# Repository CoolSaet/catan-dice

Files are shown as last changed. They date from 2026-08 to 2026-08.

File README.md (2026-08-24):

# Catan Dice – ESP8266 D1 Mini

A physical dice-roller for Catan.  
Press the button → the ESP performs an HTTP GET to a configured URL (your game server / smart home integration).

## Hardware

| Component | D1 Mini pin | Notes |
|---|---|---|
| Roll button | **D5** (GPIO 14) | Active LOW, internal pull-up enabled |

The roll button uses the D1 Mini's internal pull-up, so no external pull-up resistor is
needed.

### Assembly and Wiring

1. Stack the Wemos Li-ion Battery Shield on top of the Wemos D1 Mini.
2. Wire the push-button switch between **D5** (GPIO 14) and **GND**.
3. Wire the button LED between **GND** and **5V** on the battery shield.
4. Connect the battery to the battery shield. Cut the battery's positive wire and put the
	SPST switch in series between the two cut ends. Adding connectors to the battery cable can
	make this connection easier and allow the battery to be disconnected.

The switch must be turned on for the battery to charge. To charge the battery, connect a USB
cable to the USB port on the battery shield while the switch is on.

### Hardware Used

All hardware was bought at [TinyTronics](https://tinytronics.nl/):

* PKCELL Li-Po Battery 3.7V 2000mAh – JST-PH – LP803860
* Metal Push Button 16mm – Reset – with 3-6V Green LED – with Cable
* Xurui XT-11A Toggle Switch – SPST
* Wemos Li-ion Battery Shield for D1 Mini (Lolin v1.3.0)
* Wemos D1 Mini V4 – ESP8266 – CH340 (Lolin)

## Features

* **AP mode** – the ESP creates its own WiFi network so you can connect without a router.
* **STA mode** – the ESP connects to your home WiFi.
* **Dual STA profiles** – configure two STA WiFi profiles and choose which one is tried first.
* **STA fallback order** – try selected primary STA profile, then the other profile, then AP mode.
* The first STA profile is by default configured for the smart-catan ad hoc access point. See [CoolSaet/smart-catan](https://github.com/CoolSaet/smart-catan).
* Separate roll URLs for AP and STA modes.
* Web UI served from LittleFS to configure SSIDs, passwords and URLs at runtime.
* HTTP Basic Authentication protects the web UI, configuration API and browser roll endpoint.
* Config persisted in `/config.json` on the filesystem (survives reboots).
* Roll button is debounced (50 ms).

## Building & Flashing

Install [PlatformIO](https://platformio.org/).

```bash
# Build firmware
pio run

# Upload firmware
pio run -t upload

# Upload web UI (data/ folder) to LittleFS
pio run -t uploadfs

# Monitor serial output
pio device monitor
```

## Web UI

After flashing, connect to the ESP's IP address in a browser:

* **AP mode** – connect to the `CatanDice` WiFi, then open `http://192.168.4.1/`
* **STA mode** – find the IP from serial monitor or your router, then open `http://<ip>/`

The browser will prompt for the web username and password. The default credentials are:

* Username: `admin`
* Password: `catandice`

Change the web password from the **Web Server Authentication** section. The password field is
blank and locked until its **Change** button is clicked. A web password must contain at least
8 characters, and an empty web username is rejected.

HTTP Basic Authentication protects all web routes. Credentials are not encrypted because the
ESP serves HTTP rather than HTTPS, so use this on a trusted local network. Change the default
password before using the device on a network where other users may connect.

### REST API

| Method | Path | Description |
|---|---|---|
| `GET`  | `/config` | Returns non-secret configuration as JSON |
| `POST` | `/config` | Update configuration (JSON body) |
| `POST` | `/roll` | Trigger a dice roll from browser |

All API requests require valid HTTP Basic Authentication. `GET /config` never returns the AP,
STA, or web-server passwords. The web UI only includes a password in `POST /config` after that
password's **Change** button has been clicked; otherwise the stored password is left unchanged.
The username is returned by `GET /config` because it is not secret.

Example request:

```bash
curl --user admin:catandice http://192.168.4.1/config
```

## Default Configuration

| Setting | Default |
|---|---|
| AP SSID | `CatanDice` |
| AP Password | `catandice` |
| First STA profile SSID | `LocalCatanWiFi` (smart-catan ad hoc access point) |
| Local Catan WiFi password | `LocalCatanPass` |
| Local Catan WiFi roll URL | `http://192.168.4.1/rollDice` |
| Home WiFi SSID | *(empty)* |
| Home WiFi password | *(empty)* |
| Home WiFi roll URL | `http://catan.mydomain.eu/rollDice` |
| Primary STA profile | Local Catan WiFi |
| Web username | `admin` |
| Web password | `catandice` |

Passwords are stored in `/config.json` on LittleFS so they survive reboots, but they are not
sent back through `GET /config`. Existing configuration files without web credentials use the
defaults above.

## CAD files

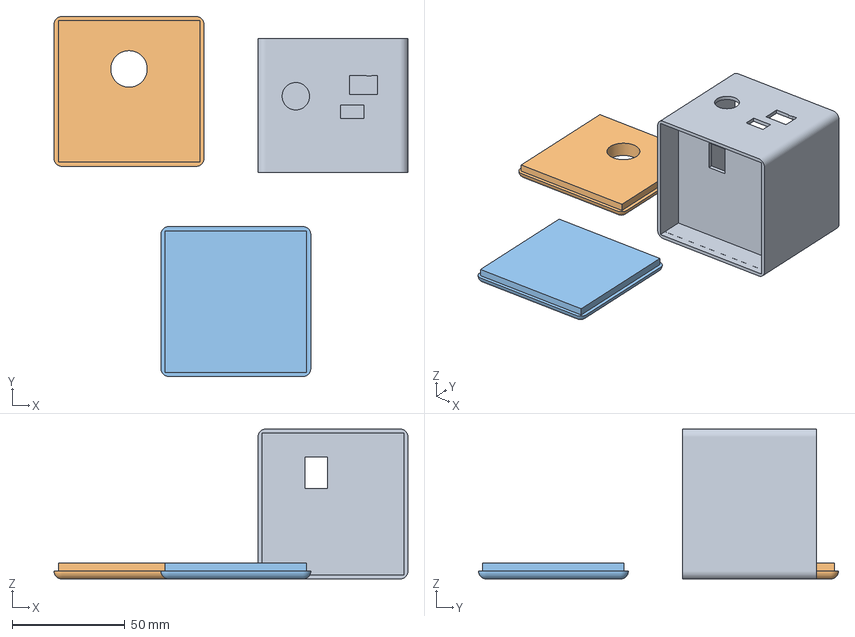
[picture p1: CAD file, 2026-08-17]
3d/Dice_w_Battery.3mf
157.2 x 159.9 x 66.6 mm
top_lid
bottom_lid

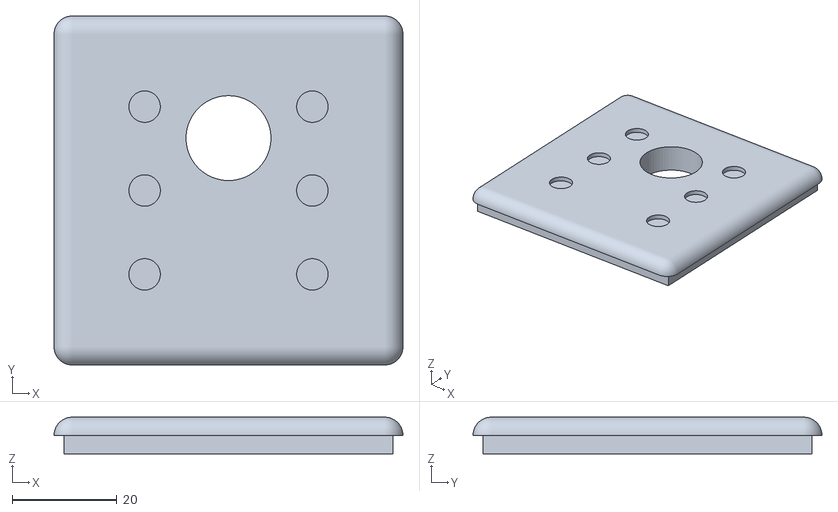
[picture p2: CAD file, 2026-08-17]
3d/top_lid.stl
66.6 x 66.6 x 7.00

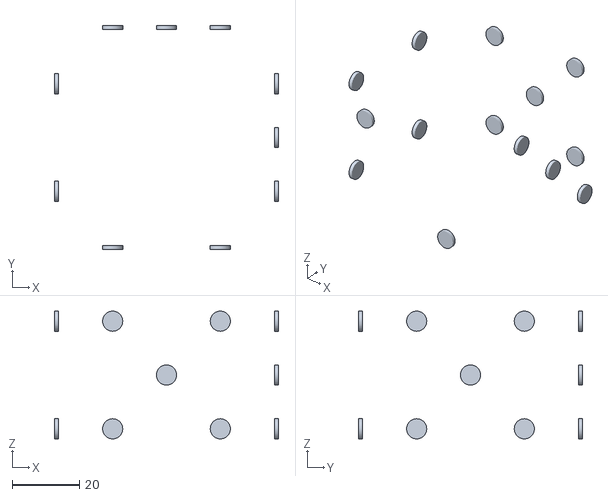
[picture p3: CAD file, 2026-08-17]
3d/body_pips.stl
66.6 x 66.6 x 38.0

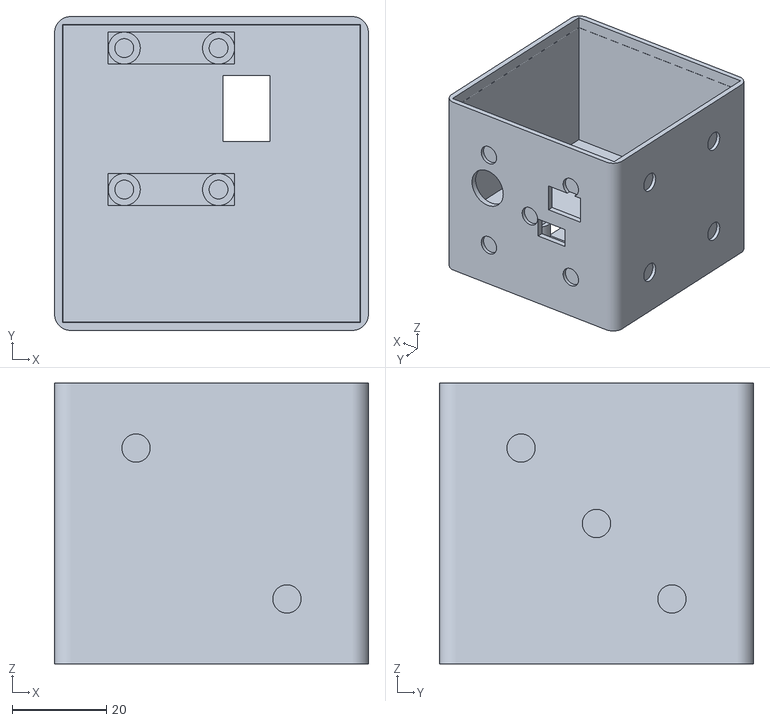
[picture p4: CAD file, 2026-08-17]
3d/body.stl
66.6 x 66.6 x 59.6

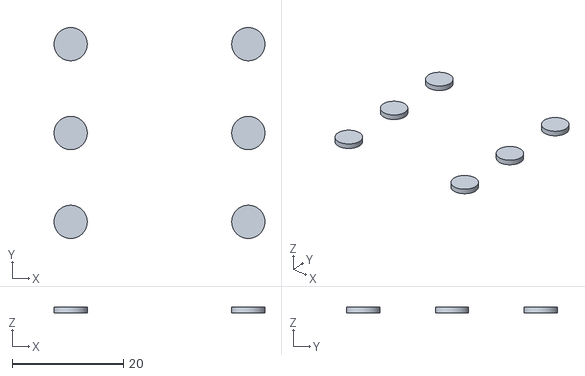
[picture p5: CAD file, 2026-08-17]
3d/top_lid_pips.stl
38.0 x 38.0 x 1.15

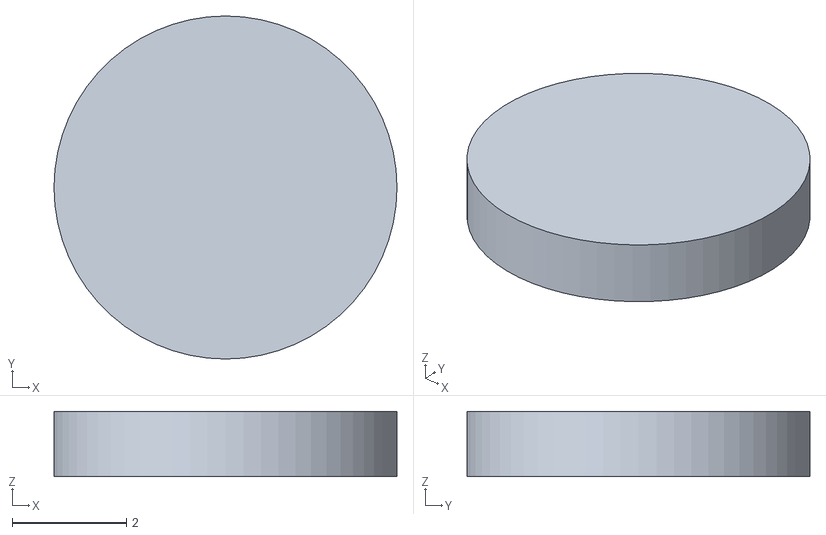
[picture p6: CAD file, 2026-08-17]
3d/bottom_lid_pips.stl
6.00 x 6.00 x 1.15

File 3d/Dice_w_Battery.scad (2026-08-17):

// ==========================================
// PARAMETRIC AMS DICE ENCLOSURE 
// (12.5mm ROUND SWITCH + EXTRA WEMOS CLEARANCE)
// ==========================================
$fn = 60; // Smoothness for circles/cylinders

/* [Render Selection] */
part = "all"; // [body_ams: Main Body (Color 1), pips_ams: All Pips (Color 2), top_lid_ams: Top Lid (Color 1), top_pips_ams: Top Lid Pips (Color 2), bottom_lid_ams: Bottom Lid (Color 1), bottom_pip_ams: Bottom Lid Pip (Color 2), all: Color Preview]

/* [Core Dimensions] */
inner_size    = 63.0; // 63mm internal cavity for 2000mAh battery
wall_thick    = 1.8;  // Wall thickness
dice_size     = inner_size + (2 * wall_thick); // 66.6mm outer cube
corner_rad    = 3.5;  // Outer rounded corner/edge radius (mm)

/* [AMS Pip Specs] */
pip_dia       = 6.0;  
pip_depth     = 0.8;  // Flush skin depth

/* [Internal Compartments] */
bat_bay_h     = 17.0; 
floor_thick   = 2.0;  

/* [Board Specs - Matched to Photo] */
wemos_w       = 25.8; // Board width
wemos_l       = 34.4; // Board length
pcb_thick     = 1.6;  
standoff_h    = 8.0;  // Standoff height above internal floor

// Mounting Holes & Threaded Inserts (Opposite USB Port)
insert_hole_dia = 4.0; // Pilot hole for M2 heat-set insert
insert_depth    = 5.0; // Depth for heat-set insert
standoff_dia    = 6.8; // Outer diameter of standoff pillar
v4_hole_spacing = 20.0; // Distance between mounting holes

// Board & Switch Layout Offsets
wemos_x_shift = -8.5; // Shifted 8.5mm to the left to free up room for chunky switch
wemos_y_shift = (inner_size/2) - (wemos_l/2) - 0.5; // Micro-USB flush against back wall
switch_x_pos  = 16.5; // Positioned on the right side of the back wall

// Ports & Cutouts
usb_c_w         = 10.5; // Micro-USB port cutout width
usb_c_h         = 6.0;  // Micro-USB port cutout height
usb_w         = 12.5; // Micro-USB port cutout width
usb_h         = 8.5;  // Micro-USB port cutout height
button_dia    = 16.2; // Top lid button hole diameter
switch_dia    = 12.2; // Round power switch hole diameter

/* [Lid Parameters] */
lid_thick     = 3.5;  // Matches corner_rad for smooth curvature transition
lip_height    = 3.5;  
clearance     = 0.15; 

// ==========================================
// RENDER CONTROL
// ==========================================

if (part == "body_ams") {
    difference() {
        dice_body();
        side_pips();
    }
} else if (part == "pips_ams") {
    intersection() {
        outer_block(dice_size - 2*lid_thick);
        side_pips();
    }
} else if (part == "top_lid_ams") {
    difference() {
        top_lid();
        top_side6_pips();
    }
} else if (part == "top_pips_ams") {
    intersection() {
        top_lid_outer();
        top_side6_pips();
    }
} else if (part == "bottom_lid_ams") {
    difference() {
        bottom_lid();
        bottom_side1_pip();
    }
} else if (part == "bottom_pip_ams") {
    intersection() {
        bottom_lid_outer();
        bottom_side1_pip();
    }
} else if (part == "all") {
    // Multi-Material Color Preview
    color("DarkSlateGray") difference() { dice_body(); side_pips(); }
    color("White") intersection() { outer_block(dice_size - 2*lid_thick); side_pips(); }
    
    translate([0, 0, dice_size/2 + 12]) {
        color("DarkSlateGray") difference() { top_lid(); top_side6_pips(); }
        color("White") intersection() { top_lid_outer(); top_side6_pips(); }
    }
    
    translate([0, 0, -dice_size/2 - 12]) {
        color("DarkSlateGray") difference() { bottom_lid(); bottom_side1_pip(); }
        color("White") intersection() { bottom_lid_outer(); bottom_side1_pip(); }
    }
}

// ==========================================
// MODULES & GEOMETRY
// ==========================================

module outer_shell() {
    minkowski() {
        cube([dice_size - 2*corner_rad, dice_size - 2*corner_rad, dice_size - 2*corner_rad], center=true);
        sphere(r=corner_rad);
    }
}

module outer_block(h_val) {
    linear_extrude(height=h_val, center=true)
        offset(r=corner_rad)
            square([dice_size - 2*corner_rad, dice_size - 2*corner_rad], center=true);
}

module top_lid_outer() {
    intersection() {
        outer_shell();
        translate([0, 0, dice_size/2 - lid_thick/2 + 0.01])
            cube([dice_size + 10, dice_size + 10, lid_thick + 0.02], center=true);
    }
}

module bottom_lid_outer() {
    intersection() {
        outer_shell();
        translate([0, 0, -dice_size/2 + lid_thick/2 - 0.01])
            cube([dice_size + 10, dice_size + 10, lid_thick + 0.02], center=true);
    }
}

module dice_body() {
    floor_z = -dice_size/2 + wall_thick + bat_bay_h;
    body_h = dice_size - 2*lid_thick;
    
    difference() {
        // Outer Body Wall
        outer_block(body_h);
        
        // Inner Cavity
        cube([inner_size, inner_size, inner_size], center=true);
            
        // Top Lid Lip Recess
        translate([0, 0, body_h/2 - lip_height/2 + 0.1])
            cube([inner_size + clearance, inner_size + clearance, lip_height + 0.2], center=true);

        // Bottom Lid Lip Recess
        translate([0, 0, -body_h/2 + lip_height/2 - 0.1])
            cube([inner_size + clearance, inner_size + clearance, lip_height + 0.2], center=true);

        // --- PORTS & CUTOUTS ---

        // Wire Pass-Through Cutout in Middle Floor
        translate([wemos_x_shift + wemos_w/2 + 3, wemos_y_shift, floor_z])
            cube([10, 14, floor_thick * 3], center=true);

        // Micro-USB-C Port Cutout (Shifted with Wemos)
        translate([wemos_x_shift, dice_size/2, floor_z + floor_thick + standoff_h + pcb_thick ])
            cube([usb_c_w, wall_thick * 3, usb_c_h], center=true);

    // Micro-USB Shield Port Cutout (Shifted with Wemos)
        translate([wemos_x_shift + -5, dice_size/2, floor_z + floor_thick + standoff_h + pcb_thick + 12 ])
            cube([usb_w, wall_thick * 3, usb_h], center=true);


        // 12.5mm Round Power Switch Cutout
        translate([switch_x_pos, dice_size/2, floor_z + floor_thick + standoff_h + pcb_thick + 7.0])
            rotate([90, 0, 0])
                cylinder(d=switch_dia, h=wall_thick * 3, center=true);
    }
    
    // Internal Divider Floor + Integrated Standoffs
    translate([0, 0, floor_z]) {
        difference() {
            union() {
                // Main Divider Plate
                cube([inner_size, inner_size, floor_thick], center=true);
                
                // Threaded Insert Standoffs attached directly onto middle plate
                translate([wemos_x_shift, wemos_y_shift, floor_thick/2]) {
                    wemos_v4_standoffs();
                }
                
                // Threaded Insert Standoffs attached directly onto middle plate
                translate([wemos_x_shift, wemos_y_shift+30, floor_thick/2]) {
                    wemos_v4_standoffs();
                }
            }
            
            // Re-apply Battery Wire Pass-Through Hole
            translate([wemos_x_shift + wemos_w/2 + 3, wemos_y_shift, 0])
                cube([10, 14, floor_thick * 4], center=true);
        }
    }
}

module wemos_v4_standoffs() {
    hole_y_pos = -wemos_l/2 ; 

    difference() {
        union() {
            // Reinforcing Base Plate tied to middle floor
            translate([0, hole_y_pos, 1.0])
                cube([v4_hole_spacing + standoff_dia, standoff_dia, 2.0], center=true);

            // 2 Standoff Pillars
            for (x = [-v4_hole_spacing/2, v4_hole_spacing/2]) {
                translate([x, hole_y_pos, standoff_h/2])
                    cylinder(d=standoff_dia, h=standoff_h, center=true);
            }
        }
        
        // Heat-Set Insert Pilot Holes
        for (x = [-v4_hole_spacing/2, v4_hole_spacing/2]) {
            translate([x, hole_y_pos, standoff_h - insert_depth/2 + 0.1])
                cylinder(d=insert_hole_dia, h=insert_depth + 0.2, center=true);
        }
    }
}
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

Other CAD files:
3d/bottom_lid.stl

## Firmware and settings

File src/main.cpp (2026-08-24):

/*
 * Catan Dice - ESP8266 D1 Mini
 *
 * Hardware:
 *   - Switch on D5 (GPIO14): LOW = AP mode, HIGH = STA (home WiFi) mode
 *   - Push button on D6 (GPIO12): active LOW (pull-up), rolls the dice (HTTP GET)
 *
 * Configuration is stored in LittleFS as /config.json
 * Web UI is served from LittleFS (/index.html)
 */

#include <Arduino.h>
#include <ESP8266WiFi.h>
#include <ESP8266WebServer.h>
#include <ESP8266HTTPClient.h>
#include <WiFiClient.h>
#include <LittleFS.h>
#include <ArduinoJson.h>

// Constants for button debounce state
static bool     lastButtonState  = HIGH;
static unsigned long lastDebounce = 0;
static const unsigned long DEBOUNCE_MS = 50;

// Pin definitions 
static const uint8_t PIN_BUTTON      = D5; // active LOW (Push button to roll dice)

// Config defaults
struct Config {
    // Ad-hoc AP mode
    char apSsid[32]     = "CatanDice";
    char apPassword[64] = "catandice";

    // STA profile 1 (home WiFi)
    char staLocalCatanSsid[32]     = "LocalCatanWiFi";
    char staLocalCatanPassword[64] = "LocalCatanPass";

    // STA profile 2 (secondary WiFi)
    char staHomeSsid[32]     = "";
    char staHomePassword[64] = "";

    // Preferred first profile when connecting in STA mode (1 or 2)
    uint8_t staPrimary    = 1;

    char urlLocalCatanSta[256] = "http://192.168.4.1/rollDice"; // called when in STA mode
    char urlHomeSta[256]       = "http://catan.mydomain.eu/rollDice"; // called when in STA mode

    // Web server HTTP Basic Auth credentials
    char webUsername[32] = "admin";
    char webPassword[64] = "catandice";
};

static Config cfg;
static ESP8266WebServer server(80);
static bool apMode = false;
static uint8_t connectedProfile = 0; // 0= Ad-hoc AP, 1= Local Catan STA, 2= Home STA

// Config persistence
static const char* CONFIG_FILE = "/config.json";

void loadConfig() {
    if (!LittleFS.exists(CONFIG_FILE)) return;
    File f = LittleFS.open(CONFIG_FILE, "r");
    if (!f) return;

    StaticJsonDocument<1024> doc;
    if (deserializeJson(doc, f) != DeserializationError::Ok) { f.close(); return; }
    f.close();

    strlcpy(cfg.apSsid,                 doc["apSsid"]                   | cfg.apSsid,               sizeof(cfg.apSsid));
    strlcpy(cfg.apPassword,             doc["apPassword"]               | cfg.apPassword,           sizeof(cfg.apPassword));
    strlcpy(cfg.staLocalCatanSsid,      doc["staLocalCatanSsid"]        | cfg.staLocalCatanSsid,    sizeof(cfg.staLocalCatanSsid));
    strlcpy(cfg.staLocalCatanPassword,  doc["staLocalCatanPassword"]    | cfg.staLocalCatanPassword,sizeof(cfg.staLocalCatanPassword));
    strlcpy(cfg.staHomeSsid,            doc["staHomeSsid"]              | cfg.staHomeSsid,          sizeof(cfg.staHomeSsid));
    strlcpy(cfg.staHomePassword,        doc["staHomePassword"]          | cfg.staHomePassword,      sizeof(cfg.staHomePassword));
    strlcpy(cfg.urlLocalCatanSta,       doc["urlLocalCatanSta"]         | cfg.urlLocalCatanSta,     sizeof(cfg.urlLocalCatanSta));
    strlcpy(cfg.urlHomeSta,             doc["urlHomeSta"]               | cfg.urlHomeSta,           sizeof(cfg.urlHomeSta));    
    strlcpy(cfg.webUsername,            doc["webUsername"]              | cfg.webUsername,          sizeof(cfg.webUsername));
    strlcpy(cfg.webPassword,            doc["webPassword"]              | cfg.webPassword,          sizeof(cfg.webPassword));
    
    cfg.staPrimary = doc["staPrimary"] | cfg.staPrimary;
    if (cfg.staPrimary != 1 && cfg.staPrimary != 2) cfg.staPrimary = 1;

}

void saveConfig() {
    File f = LittleFS.open(CONFIG_FILE, "w");
    if (!f) return;

    StaticJsonDocument<1024> doc;
    doc["apSsid"]      = cfg.apSsid;
    doc["apPassword"]  = cfg.apPassword;
    doc["staLocalCatanSsid"]     = cfg.staLocalCatanSsid;
    doc["staLocalCatanPassword"] = cfg.staLocalCatanPassword;
    doc["staHomeSsid"]    = cfg.staHomeSsid;
    doc["staHomePassword"] = cfg.staHomePassword;
    doc["staPrimary"]  = cfg.staPrimary;
    doc["urlLocalCatanSta"] = cfg.urlLocalCatanSta;
    doc["urlHomeSta"]       = cfg.urlHomeSta;
    doc["webUsername"]      = cfg.webUsername;
    doc["webPassword"]      = cfg.webPassword;

    serializeJson(doc, f);
    f.close();
}

// HTTP GET to roll URL 
void rollDice() {

    // Get the URL to call based on the connected profile
    const char* url = nullptr;
    if (connectedProfile == 1){
        url = cfg.urlLocalCatanSta;
    }else if (connectedProfile == 2){
        url = cfg.urlHomeSta;
    } else {
        Serial.println("[roll] Not in STA mode, skipping roll");
        return;
    }

    if (strlen(url) == 0) {
        Serial.println("[roll] URL not configured");
        return;
    }
    Serial.printf("[roll] GET %s\n", url);

    WiFiClient client;
    HTTPClient http;
    if (http.begin(client, url)) {
        int code = http.GET();
        Serial.printf("[roll] response: %d\n", code);
        http.end();
    } else {
        Serial.println("[roll] http.begin() failed");
    }
}

//  Web UI handlers 
bool requireAuthentication() {
    if (server.authenticate(cfg.webUsername, cfg.webPassword)) return true;
    server.requestAuthentication();
    return false;
}

void handleRoot() {
    if (!requireAuthentication()) return;
    if (LittleFS.exists("/index.html")) {
        File f = LittleFS.open("/index.html", "r");
        server.streamFile(f, "text/html");
        f.close();
    } else {
        server.send(200, "text/plain", "UI not found. Flash filesystem.");
    }
}

void handleGetConfig() {
    if (!requireAuthentication()) return;

    StaticJsonDocument<1024> doc;
    doc["apSsid"]                   = cfg.apSsid;
    doc["staLocalCatanSsid"]        = cfg.staLocalCatanSsid;
    doc["staHomeSsid"]              = cfg.staHomeSsid;
    doc["staPrimary"]               = cfg.staPrimary;
    doc["urlLocalCatanSta"]         = cfg.urlLocalCatanSta;
    doc["urlHomeSta"]               = cfg.urlHomeSta;
    doc["webUsername"]              = cfg.webUsername;
    doc["mode"]                     = apMode ? "ap" : "sta";

    String out;
    serializeJson(doc, out);
    server.send(200, "application/json", out);
}

void handleSaveConfig() {
    if (!requireAuthentication()) return;
    if (!server.hasArg("plain")) { server.send(400, "text/plain", "No body"); return; }

    StaticJsonDocument<1024> doc;
    if (deserializeJson(doc, server.arg("plain")) != DeserializationError::Ok) {
        server.send(400, "text/plain", "Invalid JSON");
        return;
    }

    if (doc.containsKey("apSsid"))                  strlcpy(cfg.apSsid,                 doc["apSsid"],                  sizeof(cfg.apSsid));
    if (doc.containsKey("apPassword"))              strlcpy(cfg.apPassword,             doc["apPassword"],              sizeof(cfg.apPassword));
    if (doc.containsKey("staLocalCatanSsid"))       strlcpy(cfg.staLocalCatanSsid,      doc["staLocalCatanSsid"],       sizeof(cfg.staLocalCatanSsid));
    if (doc.containsKey("staLocalCatanPassword"))   strlcpy(cfg.staLocalCatanPassword,  doc["staLocalCatanPassword"],   sizeof(cfg.staLocalCatanPassword));
    if (doc.containsKey("staHomeSsid"))             strlcpy(cfg.staHomeSsid,            doc["staHomeSsid"],             sizeof(cfg.staHomeSsid));
    if (doc.containsKey("staHomePassword"))         strlcpy(cfg.staHomePassword,        doc["staHomePassword"],         sizeof(cfg.staHomePassword));
    if (doc.containsKey("staPrimary")) {
        int primary = doc["staPrimary"];
        if (primary == 1 || primary == 2) cfg.staPrimary = primary;
    }
    if (doc.containsKey("urlLocalCatanSta")) strlcpy(cfg.urlLocalCatanSta, doc["urlLocalCatanSta"], sizeof(cfg.urlLocalCatanSta));
    if (doc.containsKey("urlHomeSta"))       strlcpy(cfg.urlHomeSta,       doc["urlHomeSta"],       sizeof(cfg.urlHomeSta));
    if (doc.containsKey("webUsername")) {
        const char* username = doc["webUsername"] | "";
        if (strlen(username) == 0) {
            server.send(400, "text/plain", "Web username cannot be empty");
            return;
        }
        strlcpy(cfg.webUsername, username, sizeof(cfg.webUsername));
    }
    if (doc.containsKey("webPassword")) {
        const char* password = doc["webPassword"] | "";
        if (strlen(password) < 8) {
            server.send(400, "text/plain", "Web password must be at least 8 characters");
            return;
        }
        strlcpy(cfg.webPassword, password, sizeof(cfg.webPassword));
    }

    saveConfig();
    server.send(200, "application/json", "{\"status\":\"ok\"}");
}

void handleRoll() {
    if (!requireAuthentication()) return;
    rollDice();
    server.send(200, "application/json", "{\"status\":\"rolling\"}");
}

// WiFi setup
void startAP() {
    WiFi.mode(WIFI_AP);
    WiFi.softAP(cfg.apSsid, cfg.apPassword);
    Serial.printf("[wifi] AP started: SSID=%s  IP=%s\n",
                  cfg.apSsid, WiFi.softAPIP().toString().c_str());
}


// Connect to STA profile, returns true if connected
bool connectSTAProfile(const char* label, const char* ssid, const char* password) {
    if (strlen(ssid) == 0) {
        Serial.printf("[wifi] %s skipped (empty SSID)\n", label);
        return false;
    }

    WiFi.begin(ssid, password);
    Serial.printf("[wifi] Connecting (%s) to %s", label, ssid);
    unsigned long t = millis();
    while (WiFi.status() != WL_CONNECTED && millis() - t < 15000) {
        delay(500);
        Serial.print('.');
    }

    if (WiFi.status() == WL_CONNECTED) {
        Serial.printf("\n[wifi] Connected (%s) IP=%s\n", label, WiFi.localIP().toString().c_str());
        return true;
    }

    Serial.printf("\n[wifi] %s failed\n", label);
    WiFi.disconnect();
    delay(100);
    return false;
}

// Start STA mode, try both profiles, fallback to AP if both fail
void startSTA() {
    WiFi.mode(WIFI_STA);

    bool connected = false;
    if (cfg.staPrimary == 2) {
        connected = connectSTAProfile("STA Home Profile", cfg.staHomeSsid, cfg.staHomePassword);
        if (connected) {connectedProfile = 2;}
        if (!connected) {
            connected = connectSTAProfile("STA Local Catan Profile", cfg.staLocalCatanSsid, cfg.staLocalCatanPassword);
            if (connected) {connectedProfile = 1;}
        }
    } else {
        connected = connectSTAProfile("STA Local Catan Profile", cfg.staLocalCatanSsid, cfg.staLocalCatanPassword);
        if (connected) {connectedProfile = 1;}
        if (!connected) {
            connected = connectSTAProfile("STA Home Profile", cfg.staHomeSsid, cfg.staHomePassword);
            if (connected) {connectedProfile = 2;}
        }
    }

    if (!connected) {
        Serial.println("\n[wifi] STA failed, falling back to AP");
        startAP();
        apMode = true;
        connectedProfile = 0; // Ad-hoc AP
    } else {
        apMode = false;
    }
}

// Arduino entry points
void setup() {
    Serial.begin(115200);
    delay(200);

    // Configure button pin
    pinMode(PIN_BUTTON,      INPUT_PULLUP);

    // Mount LittleFS and load config
    if (!LittleFS.begin()) {
        Serial.println("[fs] LittleFS mount failed");
    }
    loadConfig();

    // Start WiFi in STA, if fails, fallback to AP mode
    startSTA();

    // Setup HTTP server routes
    server.on("/",           HTTP_GET,  handleRoot);
    server.on("/config",     HTTP_GET,  handleGetConfig);
    server.on("/config",     HTTP_POST, handleSaveConfig);
    server.on("/roll",       HTTP_POST, handleRoll);

    // Serve static files from LittleFS
    server.onNotFound([]() {
        if (!requireAuthentication()) return;
        String path = server.uri();
        if (LittleFS.exists(path)) {
            File f = LittleFS.open(path, "r");
            String mime = "text/plain";
            if (path.endsWith(".html")) mime = "text/html";
            else if (path.endsWith(".css"))  mime = "text/css";
            else if (path.endsWith(".js"))   mime = "application/javascript";
            else if (path.endsWith(".json")) mime = "application/json";
            server.streamFile(f, mime);
            f.close();
        } else {
            server.send(404, "text/plain", "Not found");
        }
    });

    server.begin();
    Serial.println("[http] Server started on port 80");
}

// Main loop
void loop() {
    server.handleClient();

    // Debounced button read
    bool reading = digitalRead(PIN_BUTTON);
    if (reading != lastButtonState) {
        lastDebounce = millis();
    }
    if (millis() - lastDebounce > DEBOUNCE_MS) {
        static bool buttonPressed = false;
        if (reading == LOW && !buttonPressed) {
            buttonPressed = true;
            rollDice();
        } else if (reading == HIGH) {
            buttonPressed = false;
        }
    }
    lastButtonState = reading;
}

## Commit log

2026-08-11 Add 3D dice housing STL for Wemos D1 Mini
    [dice.scad, dice.stl, dice_lid.stl]
2026-08-11 Add pip plunger STL – pushable single dot that actuates button
    [dice.scad, dice.stl, dice_lid.stl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]
2026-08-17 Add Local Catan Option
    [Dice_w_Battery.3mf, Dice_w_Battery.scad, body.stl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]
